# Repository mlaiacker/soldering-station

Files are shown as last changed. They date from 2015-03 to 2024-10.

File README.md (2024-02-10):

# Soldering Station for Weller Soldering Tips

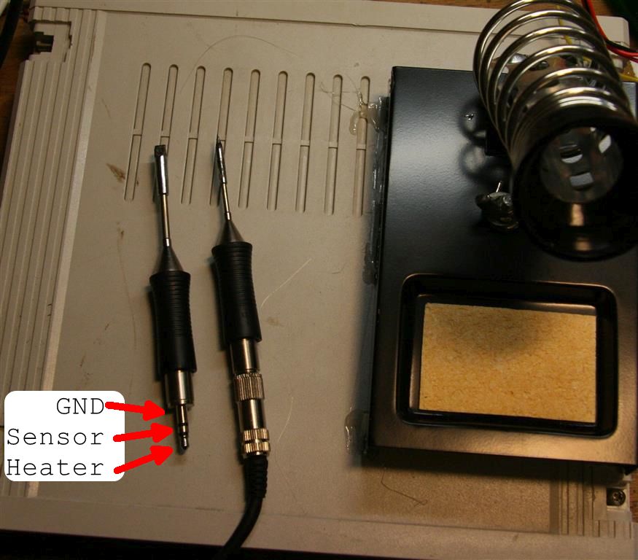
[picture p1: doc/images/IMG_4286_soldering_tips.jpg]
weller RT tips


https://www.weller-tools.com/eu/de/industrielles-loeten/produkte/loetspitzen/rtm-013-s

Power or Battery supply 10-14V DC up to 3A or so needed.

This project is based on the work of Martin Kumm.

http://www.martin-kumm.de/wiki/doku.php?id=05Misc:SMD_Solderstation

I made it simpler and cheaper. Instead of using an Arduino I use a ATmega8. This design doesn't use SMD instead a single sided PCB for easy assembly and cheap PCB production. The PCB is only 70x50mm. Instead of using two buttons to adjust the temperature I use a poti and optionally you can use a standard HD44780 compatible LCD to display temperatures. It runs on plain c (no arduino) and also includes supports a bootloader for easy firmware upgrade. The Bootloader has to be programmed befor soldering the mega8 into the PCB. The bootloader is activaded using the Boot pins on the PCB (short PD2 to ground)

http://mlaiacker.mooo.com/Elektronik/Soldering%20Station/

http://fpv-community.de/showthread.php?41335-DIY-SMD-L%F6tstation-Ersatz-f%FCr-%28WELLER%29

## PCB layout

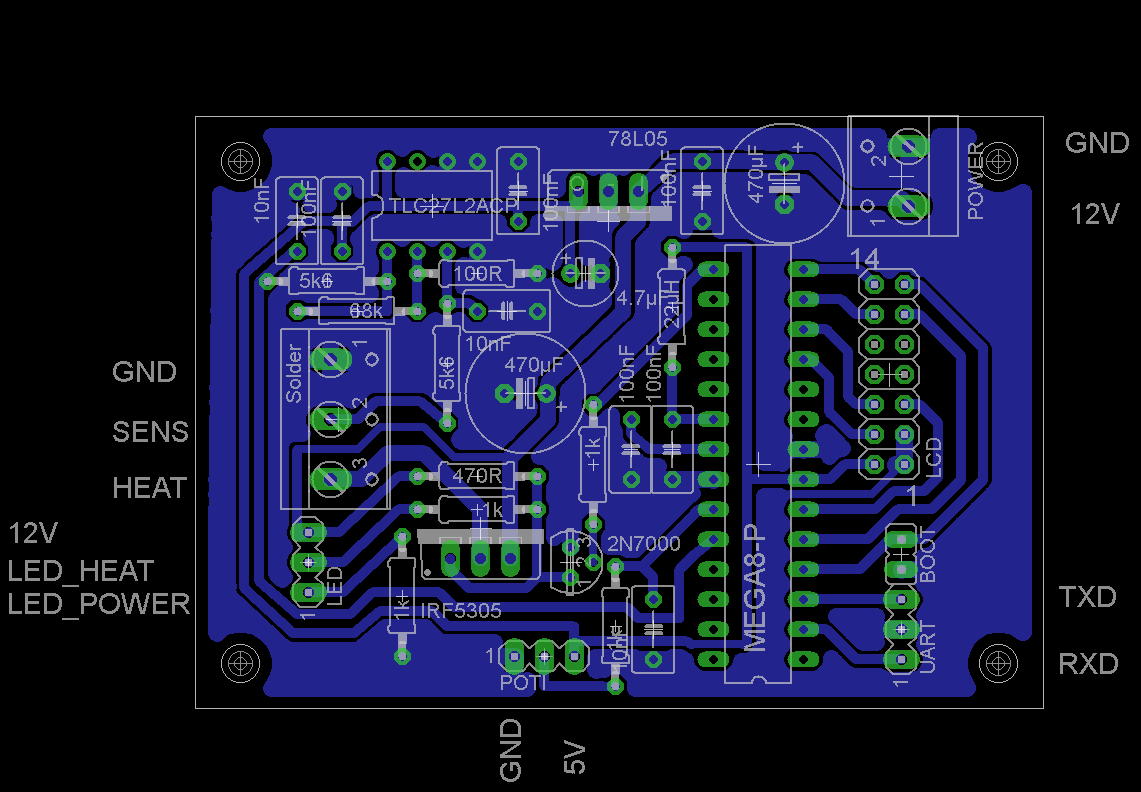
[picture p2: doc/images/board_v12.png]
Borad layout


[board layout pdf hardware/eagle/rt_solder_simple_V1.2.brd.pdf](hardware/eagle/rt_solder_simple_V1.2.brd.pdf?raw=true)

## Bill of Materials for PCB

[BOM as pdf](hardware/eagle/rt_solder_simple_V1.2.BOM.pdf?raw=true)

| Qty | Value | Device | Package | Parts | Description | Comment | Link |
| --- | --- | --- | --- | --- | --- | --- | ---- |
| 3 | 10nF | C-EU050-035X075 | C050-035X075 | C6, C7, C8 | CAPACITOR, | | |
| 5 | 100nF | C-EU050-035X075 | C050-035X075 | C3, C4, C9, C10, C11 | CAPACITOR, | | |
| 1 | TLC27L2ACP | TLC27L2ACP | DIL08 | IC3 | DUAL OPERATIONAL AMPLIFIERS | | |
| 1 | 22µH or 10R  | L-EU0207/10 | 0207/10 | L1 | INDUCTOR, | | |
| 1 | BOOT | JP1E | JP1 | JP2 | JUMPER | to enable bootloader | |
| 1 | MEGA8-P | MEGA8-P | DIL28-3 | IC1 | MICROCONTROLLER | needs bootloader | |
| 1 | 2N7000 N-CH  | VN2222KM | TO237 | Q1 | N-Channel MOSFET | | |
| 1 | IRF5305 P-CH | IRF9530 | TO220BV | Q3 | P-CHANNEL POWER-MOS-FET | | |
| 1 | LCD | PINHD-2X7 | 2X07 | JP1 | PIN HEADER | optional | |
| 1 | LED | MA03-1 | MA03-1 | SV4 | PIN HEADER | | |
| 1 | POTI | MA03-1 | MA03-1 | SV1 | PIN HEADER | Poti to set temperatur 1K-50K | |
| 1 | UART | MA03-1 | MA03-1 | SV2 | PIN HEADER | optional | |
| 1 | 4.7µF 10V | CPOL-EUE2.5-6 | E2,5-6 | C1 | POLARIZED CAPACITOR | | |
| 2 | 470µF 16V | CPOL-EUE3.5-10  | E3,5-10 | C2, C5 | POLARIZED CAPACITOR, | | |
| 1 | 100R | R-EU_0207/10 | 0207/10 | R6 | RESISTOR, | | |
| 1 | 470R | R-EU_0207/10 | 0207/10 | R2 | RESISTOR, | | |
| 1 | 68k | R-EU_0207/10 | 0207/10 | R5 | RESISTOR, | | |
| 2 | 5k6 | R-EU_0207/10 | 0207/10 | R4, R7 | RESISTOR, | | |
| 4 | 1k | R-EU_0207/10 | 0207/10 | R3, R8, R11, R12 | RESISTOR, | | |
| 1 | 47k | R-EU_0207/10 | 0207/10 | bodge | RESISTOR, | to fix tmperature measurement | |
| 1 | 10M | R-EU_0207/10 | 0207/10 | bodge | RESISTOR, | to fix tmperature measurement | |
| 1 | 10k | R-EU_0207/10 | 0207/10 | bodge | RESISTOR, | to add voltage measurement | |
| 1 | 100k | R-EU_0207/10 | 0207/10 | bodge | RESISTOR, | to add voltage measurement | |
| 1 | 78L05 | 78XXS | 78XXS | IC2 | VOLTAGE REGULATOR | | |
| 1 | POWER | W237-02P | W237-132 | X1 | WAGO SREW CLAMP | optional | |
| 1 | Solder | W237-3E | W237-3E | X2 | WAGO SREW CLAMP | optional | |

## Images

PCB<br>
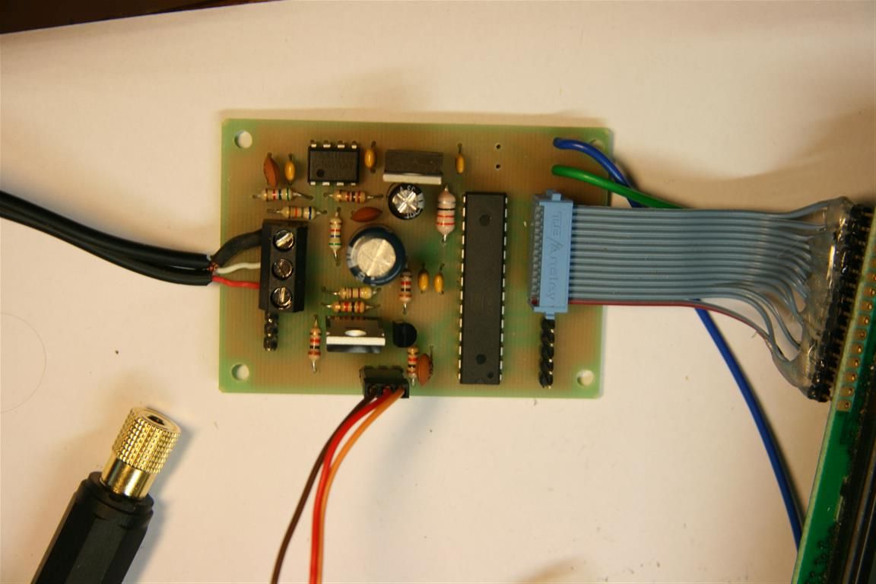
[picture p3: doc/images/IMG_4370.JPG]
max solder pcb
 <br>
With nice enclosure and LCD<br>
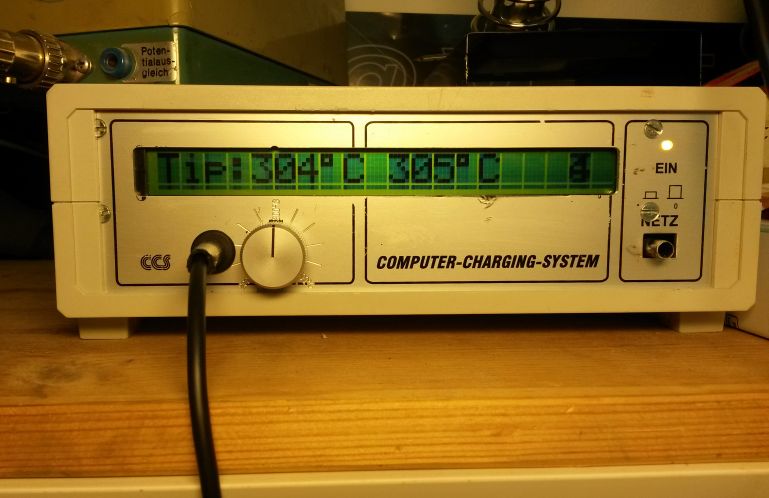
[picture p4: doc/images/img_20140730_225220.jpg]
 <br>
You can also just use this scale to set the temperature instead of the LCD
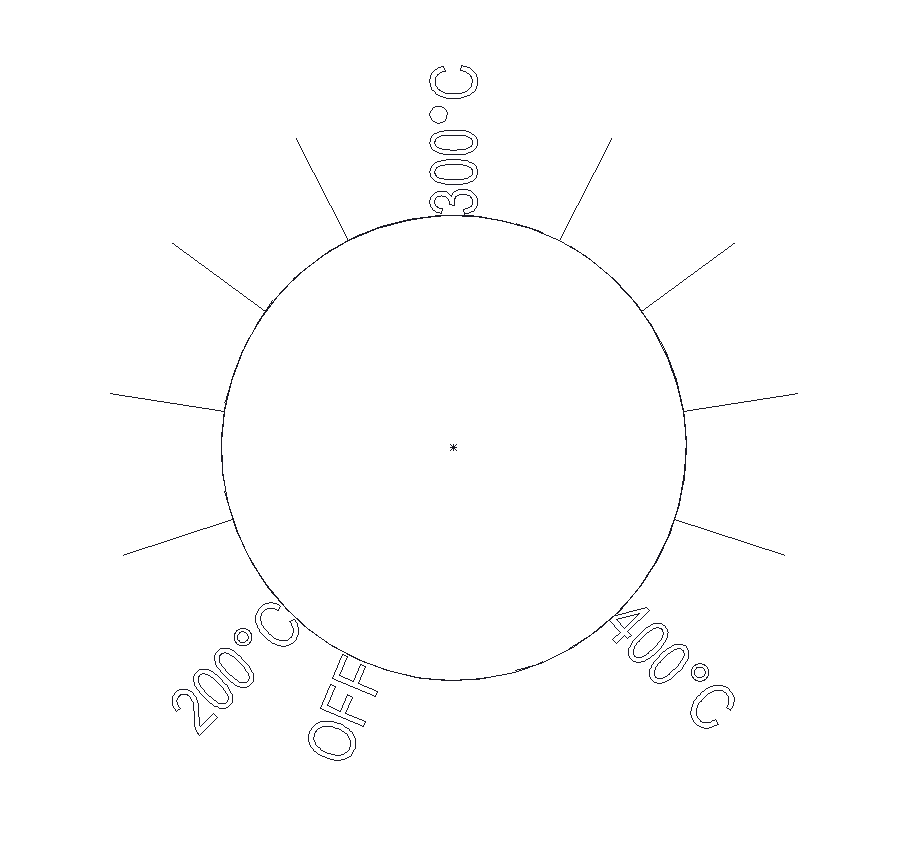
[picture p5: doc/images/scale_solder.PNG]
 <br>
Ask me for PCBs !! I had 10 made and some are available<br>
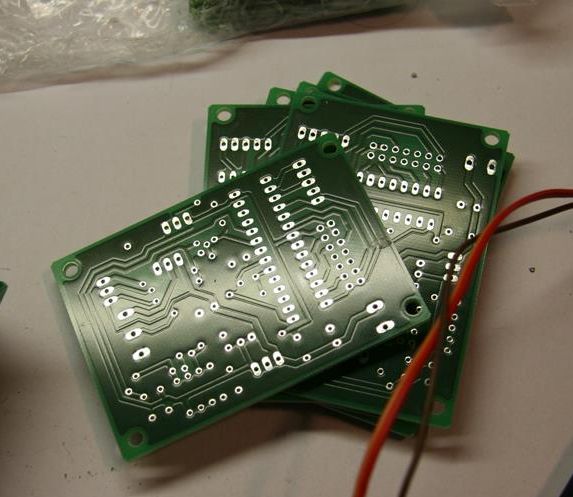
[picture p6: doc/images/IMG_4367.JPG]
PCBs
 <br>

## FAQ

### Hast du noch Platinen? 

ja noch: <br>
10 (2.4.2016)<br>
9 (5.4.2016)<br>
Ich kann auch gleich programmierten atmega8 und OPA und LCD dazu legen

### Was Kostet? 
10

### hex bauen?

```
make all
```

Das erstellen der main.hex geht über das Makefile mit "make all" dazu musst du den gcc avr Compiler installiert haben siehe dazu :http://www.mikrocontroller.net/articles/AVR-GCC

### flashen?

[for atmega 168](software/avr/main_atmega168.hex)

[for atmega 8](software/avr/main_atmega8.hex)

```
make program
```

Mit "make program" wird dann avrdude aufgerufen um über die serielle Schnittstelle ein neues Programm zu laden.
Dazu musst du wahrscheinlich den Port (com1) ändern im Makefile

```
AVRDUDE_PORT = com1 -b 38400 # programmer connected to serial device
```

Computer per TTL Seriell mit der Platine verbinden einen jumper auf die "Boot" pins stecken und einschalten dann wird der Bootloader aktiviert.

### bootloader ?

kopliziert. mit extra Adapter per ISP und dann mit "make programm_all" im bootloader Ordner. (avrdude und DIAMEX USB ISP bei mir)

### Wo bekomme ich IC3 her?

TLC 272 DIP bei reichelt

### Temperatur stimmt nicht

Die auf dem Display angezeigte Temperatur ist zu hoch bzw entspricht nicht der an der Lötspitze gemessenen. 
Bitte einen 47k Widerstand von Pin 3 an IC3 nach Masse löten und neue Software laden und wenn nötig
```C
#define TEMP_GAIN	(4980L)
#define TEMP_OFFSET	(-8)
```
anpassen.

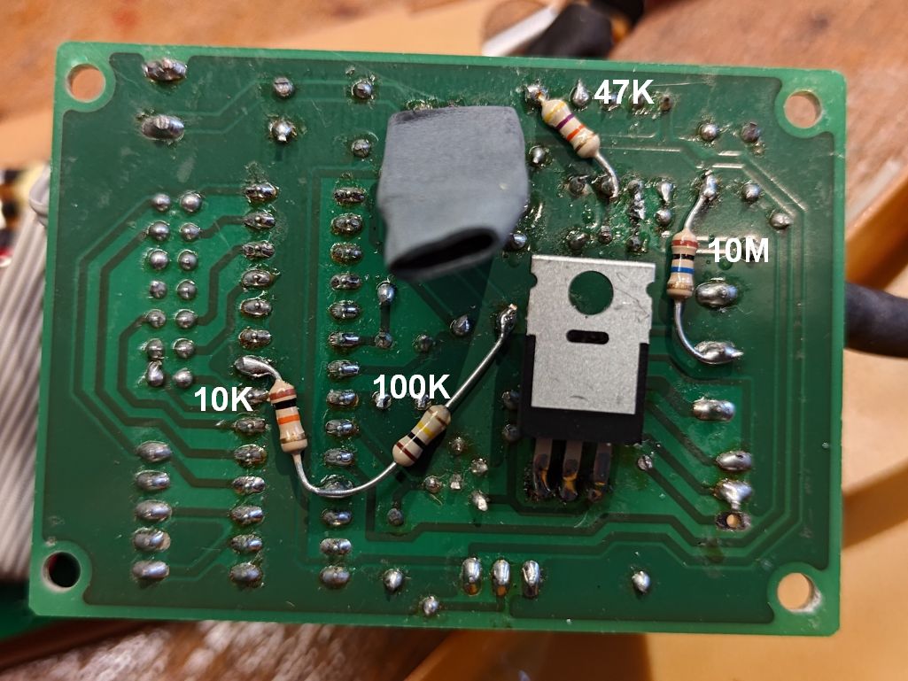
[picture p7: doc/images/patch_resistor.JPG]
PCB patch resitor placement
 <br>

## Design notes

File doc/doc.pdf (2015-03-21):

# Soldering Station for Weller Soldering Tips

This project is based on the work of Martin Kumm. (http://www.martin-kumm.de/wiki/doku.php?id=Projects:SMD_Solderstation)

I made it simpler and cheaper. Instead of using an Arduino I use a ATmega8. This design doesn't use SMD and one single Layer PCB for easy assembly and cheap PCB production and the PCB is only 70x50mm. Instead of using two Buttons to adjust the temperature I use a potentiometer and optionally you can use a standard HD44780 compatible LCD.

The PCB I designed is very easy to assemble and can also be home made. It has an optional LCD interface to display temperatures. The serial port can be used for monitoring, logging and firmware update.

These are the two tips I use for this project. They can be switched very easily and also heat up very fast.

I could not find a good and flexible cable for connecting the 3.5mm plug to the soldering station. You will need at least 3 wires and not too thin because the peak current is around 5A

I had some PCBs made and if someone wants some then please send me an e-mail.

This is one of the ordered PCB assembled and tested. While testing I wound a bug in my firmware and now it works better than before. I also made a video during the assembly.

The inside of the first prototype before installing the LCD. The transformer is from the battery charger that was in this enclosure before. It has a rated voltage of 12V at 5A. When using a smaller power supply and no LCD you can use a much smaller enclosure. Bu I had that laying around for more then 10 years and finally I found a new use for it.

This is the first prototype I made. The enclosure and the power supply I had laying around. On top you can see my old Ersa TE50 soldering station that I used to build the new one.

Front view of the prototype with LCD and the knob to adjust the temperature.

I used a CNC mill to make the holes and to engrave the scale for the temperature adjustment knob. The temperature can be adjusted from 200°C to 400°C. If you turn the nob below the 200 mark the heater is turned off.

This is a plot of the soldering iron heating up. Here for the big 50W tip. It only takes 14 seconds to heat up and here the heating current was limited to about 50%.

This is the response for the small tip and here it only needs 6 seconds to heat from room temperature to 340°C. It has a small overshoot when heating up from room temperature but I think it's the controller is tuned good enough. Maybe I could implement a estimator for the temperature but that would be overkill.

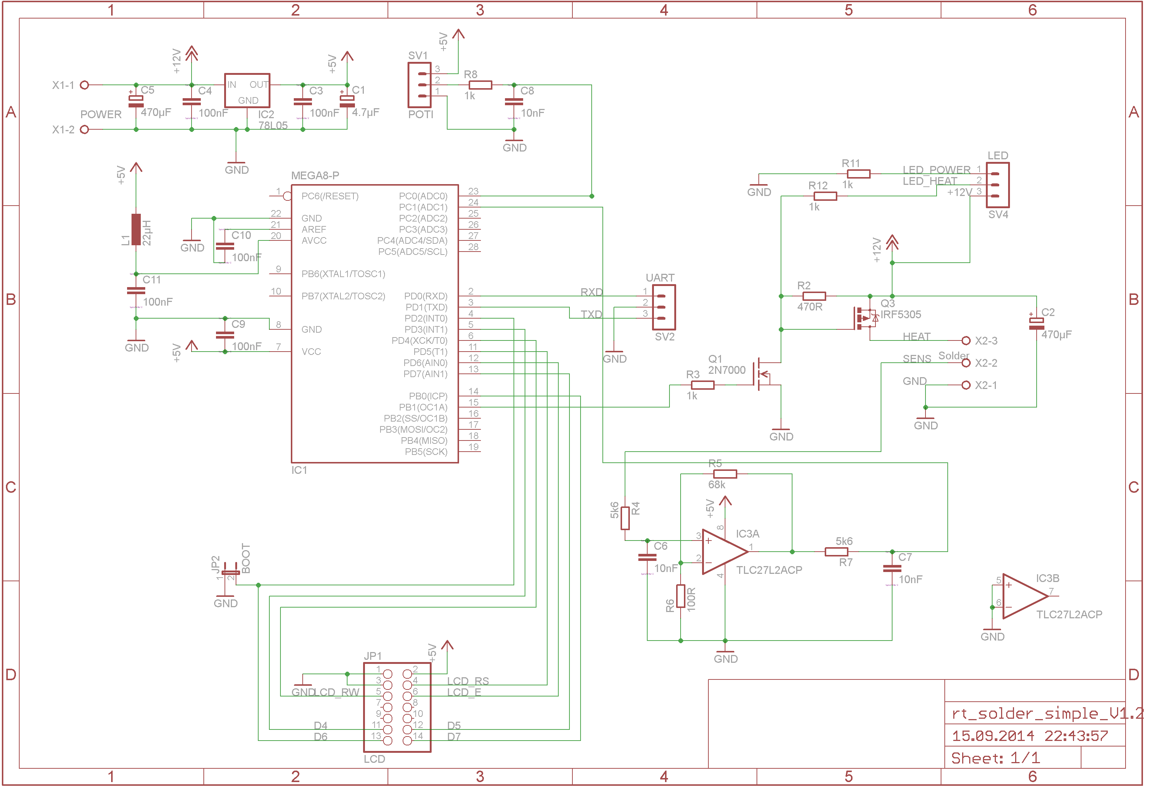
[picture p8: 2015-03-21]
hardware/eagle/schv12.png

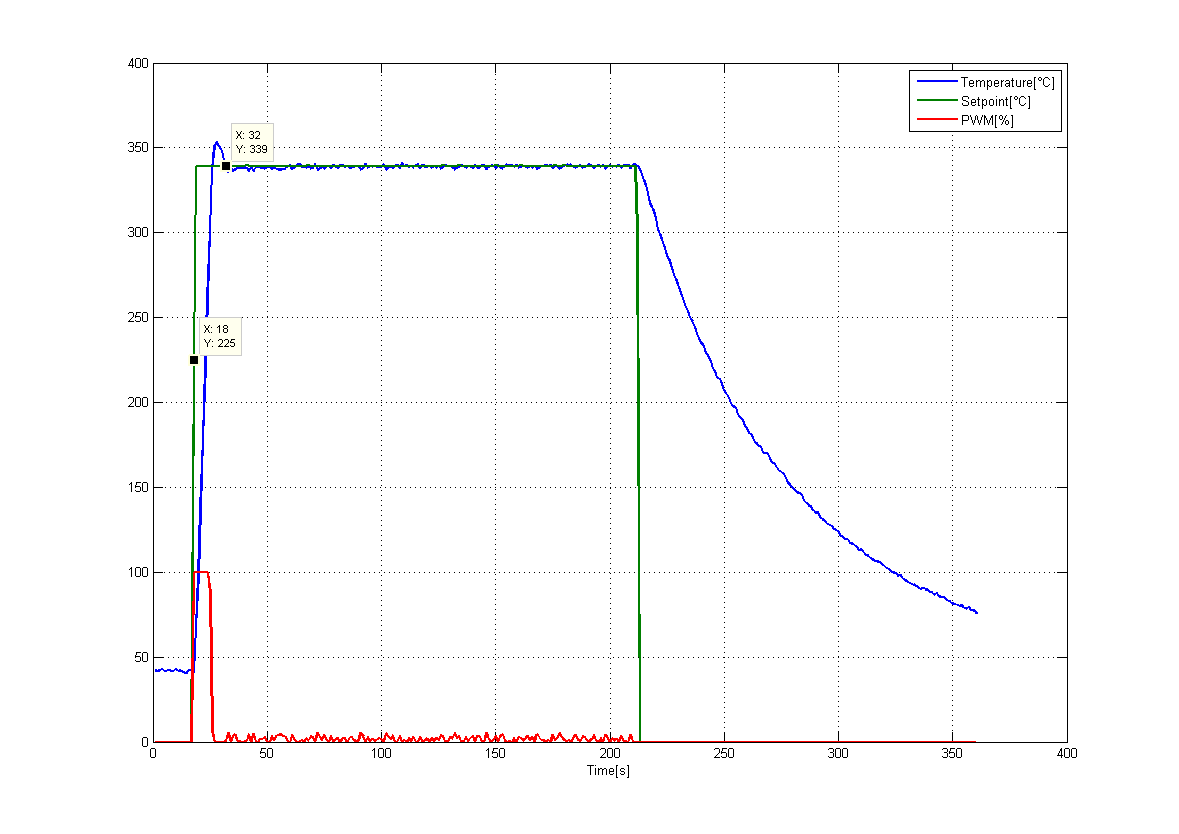
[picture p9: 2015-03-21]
doc/images/plot_tip1.png

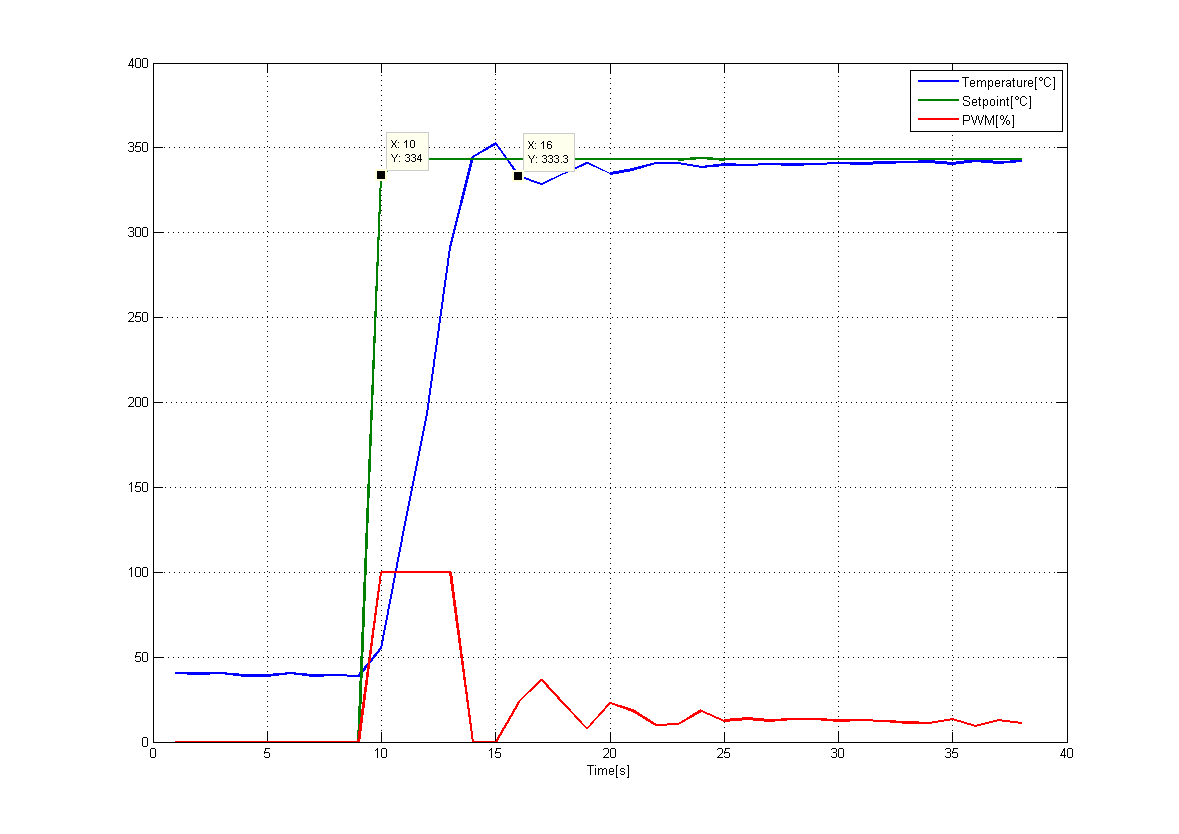
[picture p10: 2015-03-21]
doc/images/plot_tip2.png

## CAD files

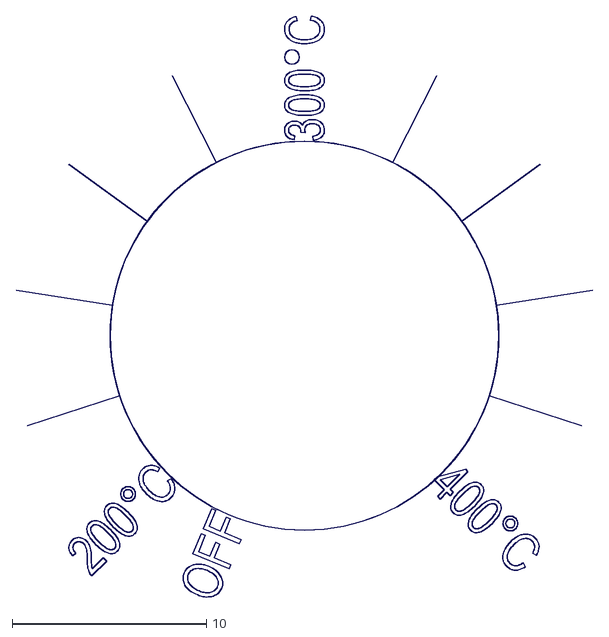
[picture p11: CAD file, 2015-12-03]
doc/images/scale_solder.DXF
29.6 x 29.9

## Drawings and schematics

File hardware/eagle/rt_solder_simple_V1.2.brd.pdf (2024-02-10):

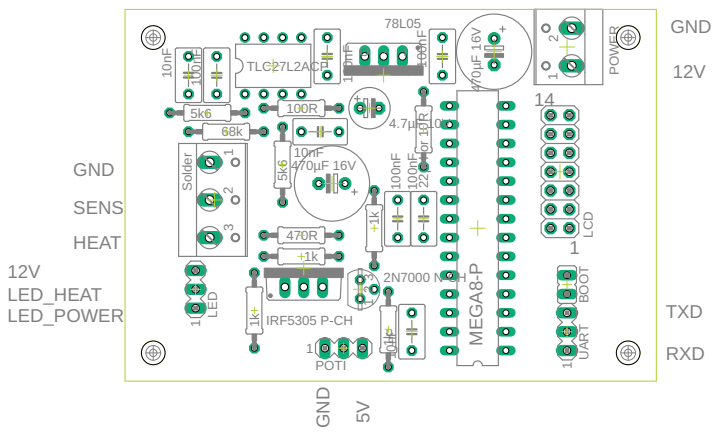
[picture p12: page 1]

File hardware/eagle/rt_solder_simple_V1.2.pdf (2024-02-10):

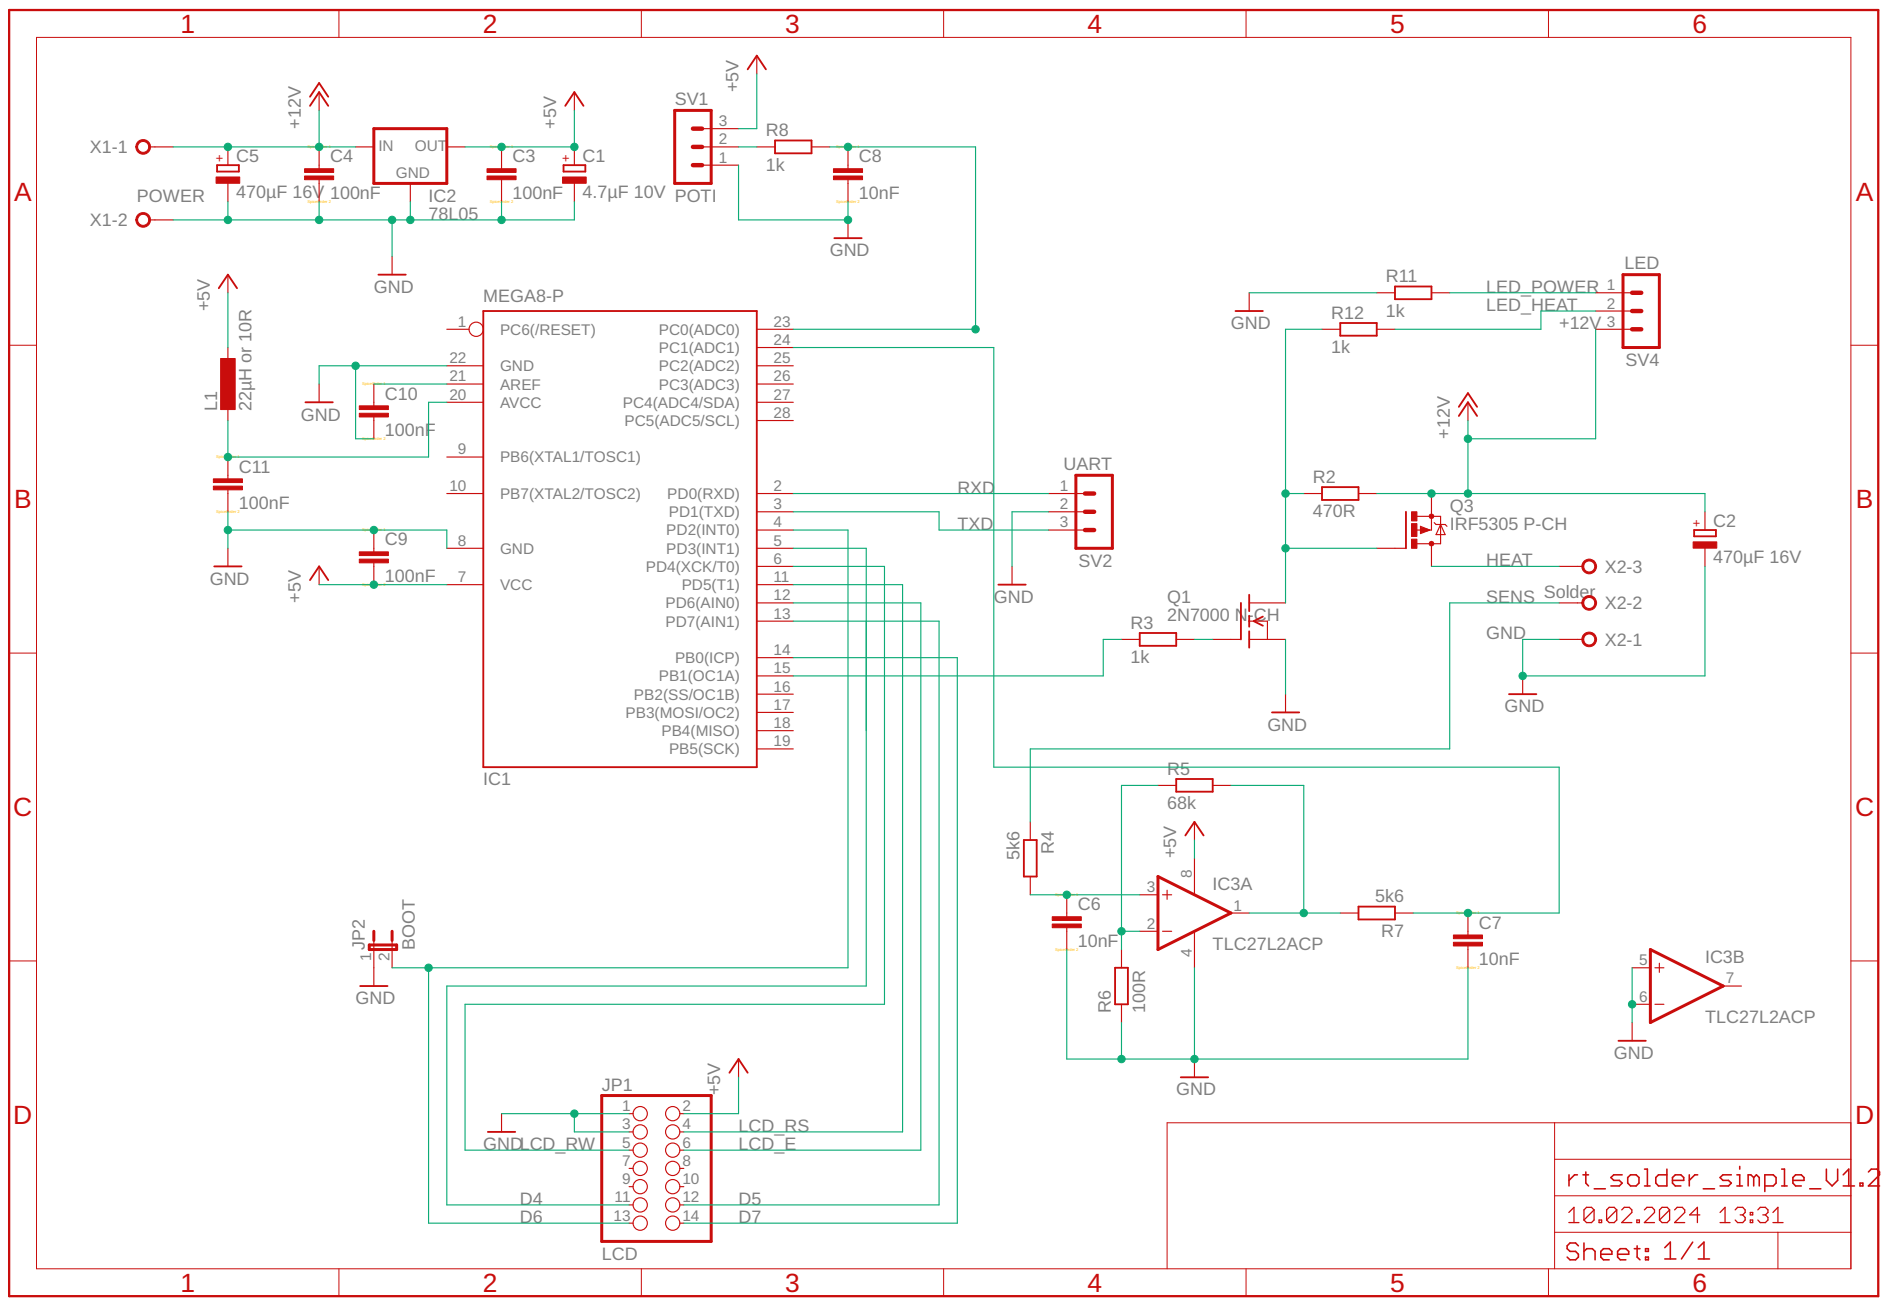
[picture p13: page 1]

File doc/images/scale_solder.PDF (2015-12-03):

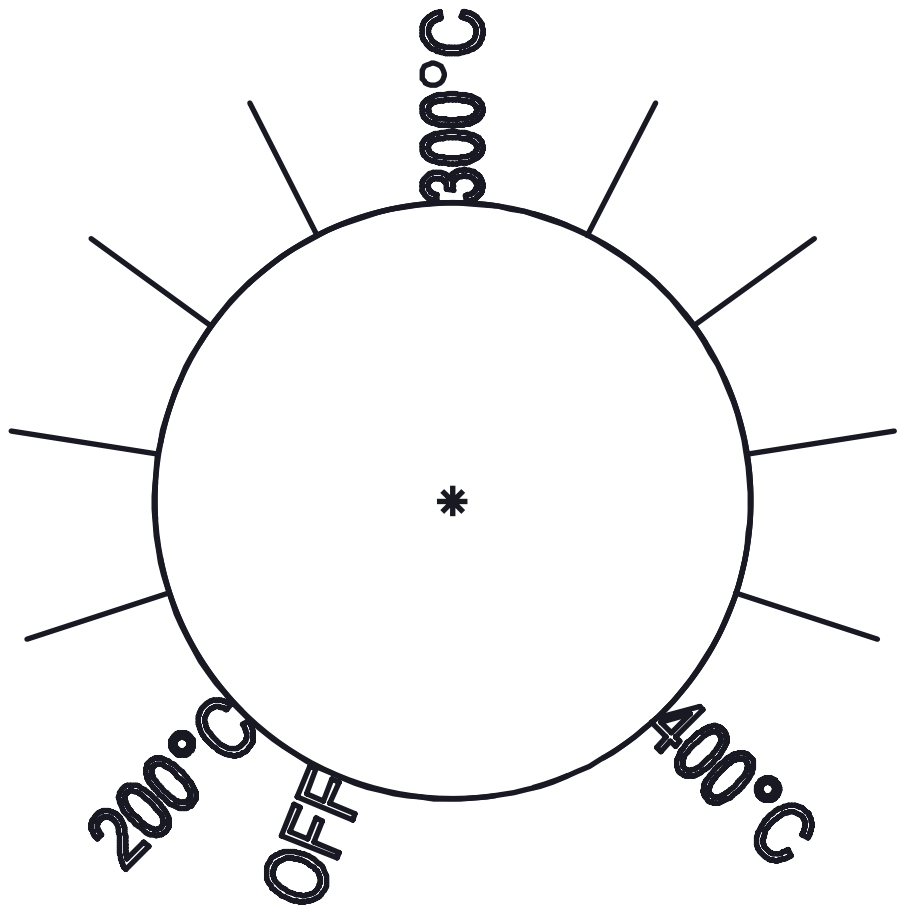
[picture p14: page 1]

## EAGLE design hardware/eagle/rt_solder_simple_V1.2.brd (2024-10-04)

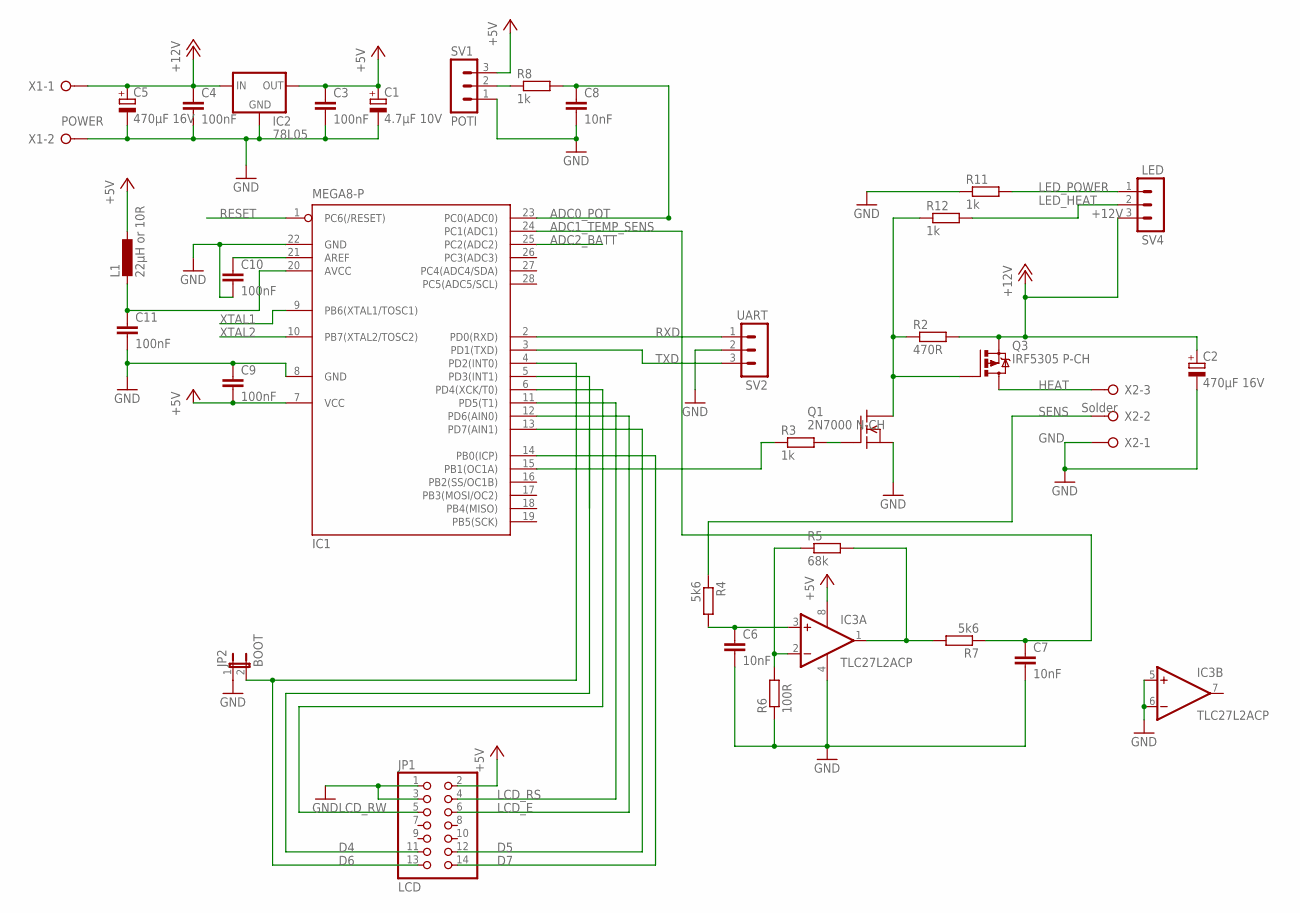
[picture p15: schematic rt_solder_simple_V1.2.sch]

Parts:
C1: 4.7µF 10V; E2,5-6
C2, C5: 470µF 16V; E3,5-10
C3, C4, C9, C10, C11: 100nF; C050-035X075
C6, C7, C8: 10nF; C050-035X075
IC1: MEGA8-P; DIL28-3
IC2: 78L05; 78XXS
IC3: TLC27L2ACP; DIL08
JP1: LCD; 2X07
JP2: BOOT; JP1
L1: 22µH or 10R; 0207/10
Q1: 2N7000 N-CH; TO237
Q3: IRF5305 P-CH; TO220BV
R2: 470R; 0207/10
R3, R8, R11, R12: 1k; 0207/10
R4, R7: 5k6; 0207/10
R5: 68k; 0207/10
R6: 100R; 0207/10
SV1: POTI; MA03-1
SV2: UART; MA03-1
SV4: LED; MA03-1
X1: POWER; W237-132
X2: Solder; W237-3E

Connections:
+5V: C1.+, C3.1, C9.2, IC1.7 (VCC), IC2.OUT, IC3.8 (VDD), JP1.2, L1.1, SV1.3
+12V: C2.+, C4.1, C5.+, IC2.IN, Q3.S, R2.2, SV4.3, X1.1
ADC0_POT: C8.1, IC1.23 (PC0(ADC0)), R8.2
ADC1_TEMP_SENS: C7.1, IC1.24 (PC1(ADC1)), R7.1
ADC2_BATT: IC1.25 (PC2(ADC2))
D4: IC1.5 (PD3(INT1)), JP1.11
D5: IC1.13 (PD7(AIN1)), JP1.12
D6: IC1.4 (PD2(INT0)), JP1.13, JP2.2
D7: IC1.14 (PB0(ICP)), JP1.14
GND: C1.-, C2.-, C3.2, C4.2, C5.-, C6.2, C7.2, C8.2, C9.1, C10.2, C11.2, IC1.8 (GND), IC1.22 (GND), IC2.GND, IC3.4 (GND), IC3.5 (+IN), IC3.6 (-IN), JP1.1, JP1.3, JP2.1, Q1.3 (S), R6.1, R11.1, SV1.1, SV2.2, X1.2, X2.1
HEAT: Q3.D, X2.3
LCD_E: IC1.12 (PD6(AIN0)), JP1.6
LCD_RS: IC1.11 (PD5(T1)), JP1.4
LCD_RW: IC1.6 (PD4(XCK/T0)), JP1.5
LED_HEAT: R12.2, SV4.2
LED_POWER: R11.2, SV4.1
unnamed: Q1.1 (D), Q3.G, R2.1, R12.1
unnamed: Q1.2 (G), R3.2
unnamed: C6.1, IC3.3 (+IN), R4.2
unnamed: IC3.2 (-IN), R5.1, R6.2
unnamed: IC3.1 (OUT), R5.2, R7.2
unnamed: IC1.15 (PB1(OC1A)), R3.1
unnamed: R8.1, SV1.2
unnamed: C11.1, IC1.20 (AVCC), L1.2
unnamed: C10.1, IC1.21 (AREF)
RESET: IC1.1 (PC6(/RESET))
RXD: IC1.2 (PD0(RXD)), SV2.1
SENS: R4.1, X2.2
TXD: IC1.3 (PD1(TXD)), SV2.3
XTAL1: IC1.9 (PB6(XTAL1/TOSC1))
XTAL2: IC1.10 (PB7(XTAL2/TOSC2))

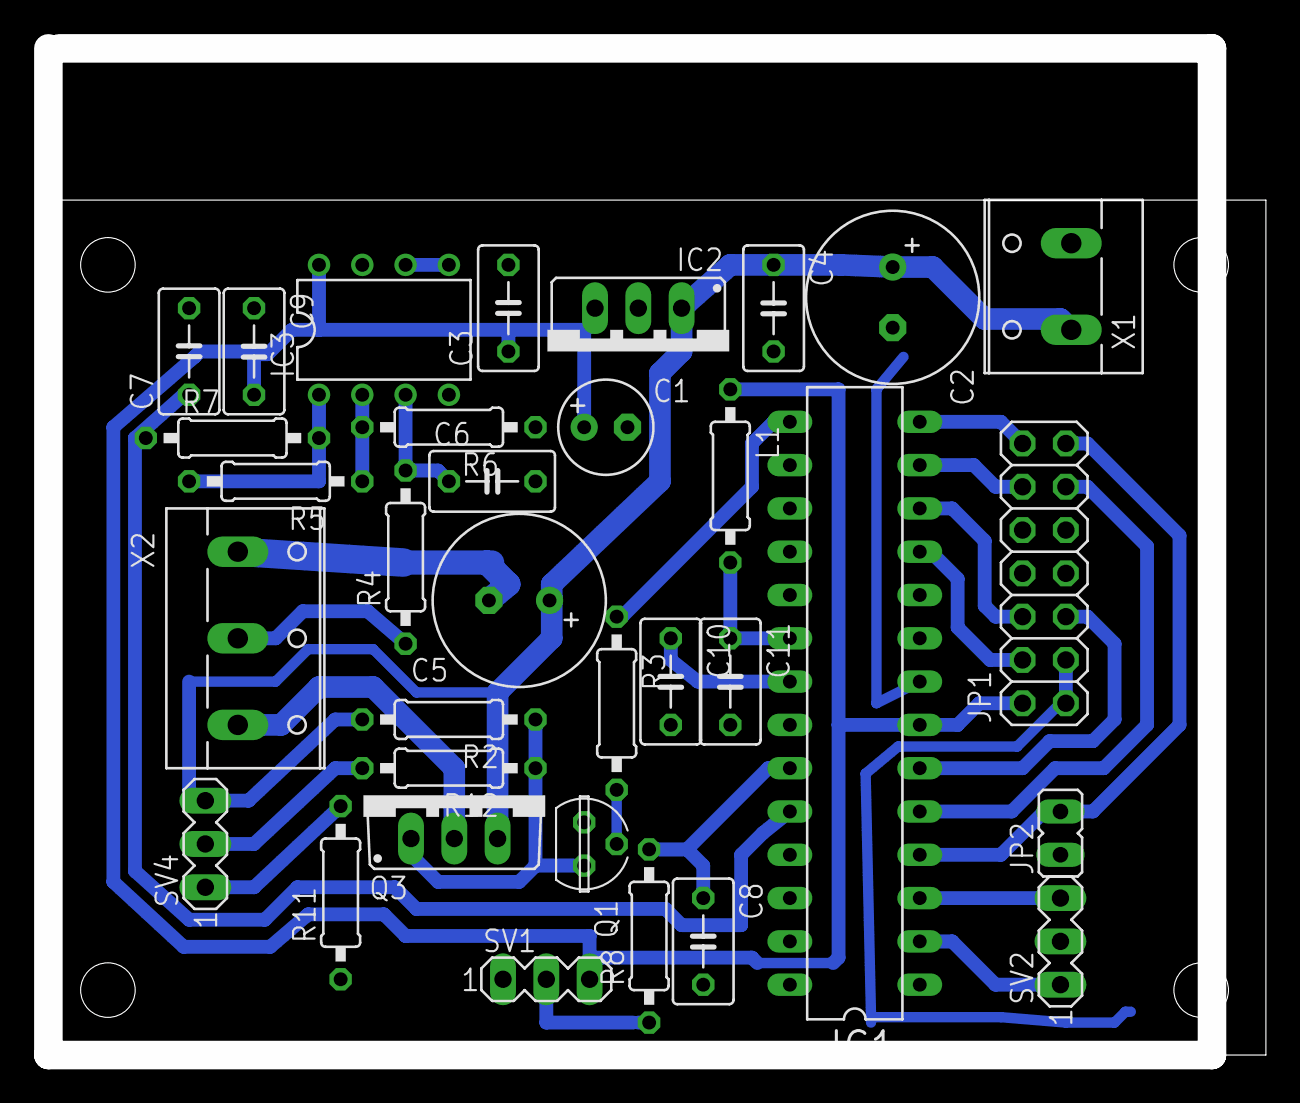
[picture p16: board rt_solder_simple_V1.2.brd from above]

Board: 2 copper layers, 71.7 x 50.2 mm, 33 parts (0 on the bottom side), 27 nets.

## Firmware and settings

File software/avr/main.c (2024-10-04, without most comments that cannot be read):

/*	 main.c
* max-Lader 
* entwickelt von:
* Maximilian Laiacker post@mlaiacker.de http://mlaiacker.de/
*
*/
#include <stdint.h>
#include <avr/interrupt.h>
#include <avr/io.h>
#include <avr/wdt.h> 
#include <avr/eeprom.h>

#include "global.h"
#include "usart.h"
#include "a2d.h"
#include "lcd.h"
#include "pwm.h"
#include "rtc.h"

#define LCD_2X16	1

#ifdef LCD_2X16
//#define LCD_SHOW_TIMEOUT // show timout counter (only on 2x16 LCD)
#endif

// for control
#define GAIN_KP 60L
#define GAIN_KI 1L
// for user input
#define POTI_OFF	10L			// bis zu diesem Wert Heizung aus
#define POTI_TEMP_START	200L	// Beginn das Poti temperatur bereich (L damit es keinen 16bit integer overflow gibt bei 1024*200/1024)
#define POTI_TEMP_END	400L	// Ende des Poti Temeratur bereich (Hardware erlaubt ca. 415 max)

#define SOLDER_MAX 	4100	// degC*10 2000==200.0degC Heizung abschalten wenn gemessene Temperatur so hoch ist
#define SOLDER_TEMP_STANDBY	(2000) // degC*10 2000==200.0degC
// gain
#define TEMP_GAIN	(4980L)
#define TEMP_OFFSET	(-8)
// standby
#define SOLDER_TIMEOUT		600 // seconds
#define SOLDER_TIMEOUT_OFF 	(SOLDER_TIMEOUT*10)
#define SOLDER_TIMEOUT_PWM_DIFF		20	// max pwm deviation around 10 second mean
#define SOLDER_TIMEOUT_TEMP_ERROR	50	// max temp deviation around setpoint in deg/10
// max heating power
#define SOLDER_MAX_PWM	(PWM_MAX_1A*2L/3L)

#define MENU_DISPLAY_INT	50 //ms
#define INT_CONTROL			16 //ms


struct
{
	t_Time tSekunde,tDisplay,tControl;
	char blinken;
	char menu_on;
	char menu_item;
} maindata;

struct {
	signed short pwm;
	signed short pwm_mean;
	signed short temp_des;
	signed short temp;
	int error_signal,i;
	char error;
	char standby;
	uint8_t	vinConnected; // voltage divider for input voltage measurement detected
	short Tpwm, Tstandby, Toff;

	char state;
	char on;
	unsigned short poti, poti_old;
	uint16_t	vin_dV; // input voltage in deci Volt
	uint16_t	vinSum;
	uint16_t    vinCount;
} solder;

typedef struct
{
	unsigned short pwm_max; // in prozent 10..99
	unsigned char poti_offset; // in adc ticks 0..1023
	unsigned char lcd_mode; // 0 = disable 1 = 1x20 2=2x16
	unsigned char control_freq; // temperature measurment freq 4..50
	unsigned short temp_low; // minimal temp for poti in deg c 1..SOLDER_MAX/10
	unsigned short temp_high; // max temp for poti 1..SOLDER_MAX/10
	unsigned short standby_timeout; // in seconds 0..6000 10<disable
	unsigned short standby_temp; // in deg c 1..temp_high
	unsigned short standby_fact; // in fact from 0..10 0=disable 5 = normal 10=big changes will reset standby counter
	short control_p; // control p gain 1..100
	short control_i; // control i gain 0..10
	short temp_sens_offset; // -100..100
	short temp_sens_gain; // 3000..6000
	unsigned int checksum; //sum off all values  + 0xabcdef
} solder_param_t;

solder_param_t param;
solder_param_t param_ee EEPROM;

unsigned int paramChecksum(solder_param_t *param);
void paramSave(void);
void paramLoad(void);

void uartOutputHeader(void);
void uartOutput(void);


//-------------Initalisierung------------------
// da die init fuktionen sowiso nur ein mal im programm aufgerufen werden stehen sie hier "inline"

void init(void){
	#ifdef BEEP_ON
	BEEP_INIT;
	#endif
	
	#ifdef UART
// Serielle Schnittstelle intalisieren
	#if defined (__AVR_ATmega168__)
		UBRRL = (uint8_t)(F_CPU/(UART_BAUD_RATE*8L)-1);
		UBRRH = (F_CPU/(UART_BAUD_RATE*8L)-1) >> 8;
		UCSR0A = _BV(U2X0);
		UCSR0B = _BV(TXEN)|_BV(RXEN)|_BV(RXCIE);
                       // Receiver enabled, Transmitter enabled
                       // RX Complete interrupt enabled
	#elif defined (__AVR_ATmega8__)
		UBRRL = (uint8_t)(F_CPU/(UART_BAUD_RATE*8L)-1);
		UBRRH = (F_CPU/(UART_BAUD_RATE*8L)-1) >> 8;
		UCSRA = _BV(U2X);
		UCSRB = _BV(TXEN)|_BV(RXEN)|_BV(RXCIE); // rx, tx, rx int
		sbi(PORTD,0);// enable pull up on rx pin
	#endif

	#endif

	Time=0;
	// Counter Register
	TCNT0=RTC_START_VAL;
	// Overflow enable
	#ifdef TIMSK
	TIMSK |= _BV(TOIE0);
	#else
	TIMSK0 |= _BV(TOIE0);
	#endif
	#ifdef TCCR0
	// prescaler select F_CPU/256
	// ergibt einen overflow alle 16MHz/256/250 = 4 ms
#if RTC_PRESCALER == 256
	TCCR0 = 0x04;
#elif RTC_PRESCALER == 64
	TCCR0 = 0x03;
#endif
	#else
	TCCR0B = 0x04;
	#endif
	
	
	ADMUX = (0<<ADLAR) | (ADC_REFERENCE<<6);
	ADCSR = ((0<<ADFR)|(1<<ADEN)|(1<<ADIE)|(1<<ADSC)|(1<<ADIF) | ADC_PRESCALE);

	pwmInit1A();
  
	sei(); // interupt enable

	//TASTE_M_INIT;
	wdt_enable(WDTO_1S);

	wdt_reset();
	paramLoad();
	if(param.checksum != paramChecksum(&param))
	{
	 // defaults
		usartPrint("loading default params...\r\n");
		param.control_p = GAIN_KP;
		param.control_i = GAIN_KI;
		param.control_freq = 10;
		param.poti_offset = POTI_OFF;
		param.lcd_mode = 1;
		param.pwm_max = SOLDER_MAX_PWM;
		param.standby_fact = 5;
		param.standby_temp = 200;
		param.standby_timeout = 600;
		param.temp_high = POTI_TEMP_END;
		param.temp_low = POTI_TEMP_START;
		param.temp_sens_gain = TEMP_GAIN;
		param.temp_sens_offset = TEMP_OFFSET;
		paramSave();
	}
	solder.vinConnected = 1;
	wdt_reset();
	usartPrint("# Max Solder build date:"__DATE__);
	usartPrint(", Git version: "GIT_VERSION"\r\n");

#ifdef LCD_CLR
	wdt_reset();
	lcdInit();
	rtcDelay(100);
	wdt_reset();
	lcdGotoY(0);
	#if defined (__AVR_ATmega168__)
		lcdPrint("   MAX-Solder16  ");
	#elif defined (__AVR_ATmega8__)
		lcdPrint("   MAX-Solder    ");
	#endif
#ifdef LCD_2X16
	lcdGotoY(1);
	lcdPrint("B:"__DATE__);
#endif
	wdt_reset();
	rtcDelay(300);
	wdt_reset();
	rtcDelay(300);
	wdt_reset();
	rtcDelay(300);
	wdt_reset();
	lcdGotoY(1);
	lcdPrint("Git:"GIT_VERSION"     ");
	rtcDelay(300);
	wdt_reset();
	rtcDelay(300);
	wdt_reset();
#endif
	uartOutputHeader();
}// init end

/*---------------- Functions -------------------------*/
void paramSave(void)
{
		param.checksum = paramChecksum(&param);
		eeprom_write_block(&param, &param_ee, sizeof(param));
}

void paramLoad(void)
{
	eeprom_read_block(&param,&param_ee,sizeof(param));
}

unsigned int paramChecksum(solder_param_t *param)
{
	unsigned int result = 0xabcd,i;
	for(i=0;i<sizeof(*param)-sizeof(param->checksum);i++)
	{
		result += ((unsigned char*)param)[i];
	}
	return result;
}

#ifdef UART

void uartOutputHeader(void)
{
	usartPrint("\r\ntemp temp_desired pwm timeout Vin\r\n");
}

void uartOutput(void)
{
	usartNum(solder.temp,4,1); // Temp
	usartNum(solder.temp_des,4,1); // Ausgangsstrom
	usartNum(solder.pwm,3,0);
	usartNum(solder.Toff,4,0);
	usartNum(solder.vin_dV,3,1);
	usartPutc('\r');
	usartPutc('\n');
}

int paramEdit(int param, int step , int min, int max, char key){
	if(key=='+'){
		param += step;
	}
	if(key=='-'){
		param -= step;
	}
	param = MAX(min, param);
	param = MIN(max, param);
	return param;
}

void uartMenu(char key)
{
	if(maindata.menu_item == 0)
	{
		if(key>='1' && key<='9')
		{
			maindata.menu_item = key - '0';
		} else {
			usartPrint("Solder Menu:\r\n");
			usartPrint("## PARAMTER ## (select 1-9 and then +- to edit)");
			usartPrint("\r\n1 P=");usartNum(param.control_p,3,0);
			usartPrint("\r\n2 I=");usartNum(param.control_i,3,0);
			//usartPrint("\r\n4 interval=");usartNum(param.control_freq,3,0);
			usartPrint("\r\n5 sens gain=");usartNum(param.temp_sens_gain,5,0);
			usartPrint("\r\n6 sens offset=");usartNum(param.temp_sens_offset,4,0);
			usartPrint("\r\nsave:s");
			usartPrint("\r\nload:l");
			usartPrint("\r\nexit:q\r\n");
		}
	} 
	{
		switch (maindata.menu_item)
		{
		case 1:
			param.control_p = paramEdit(param.control_p, 1, 1, 200, key);
			usartPrint("\r\n1 P=");usartNum(param.control_p,3,0);
			break;

		case 2:
			param.control_i = paramEdit(param.control_i, 1, 0, 20, key);
			usartPrint("\r\n2 I=");usartNum(param.control_i,3,0);
			break;
		case 5:
			param.temp_sens_gain = paramEdit(param.temp_sens_gain, 10, 3000, 6000, key);
			usartPrint("\r\n5 sens gain=");usartNum(param.temp_sens_gain,5,0);
			break;
		case 6:
			param.temp_sens_offset = paramEdit(param.temp_sens_offset, 2, -100, 100, key);
			usartPrint("\r\n6 sens offset=");usartNum(param.temp_sens_offset,4,0);
			break;
		
		default:
			break;
		}
	}
	if(key=='q'){
		maindata.menu_on = 0;
		uartOutputHeader();
		maindata.menu_item = 0;
	} 
	if(key=='s'){
		paramSave();
		maindata.menu_on = 0;
		uartOutputHeader();
		maindata.menu_item = 0;
	} 
	if(key=='l'){
		paramLoad();
		maindata.menu_item = 0;
	} 
}

#endif
/*----------------------------------------------------*/

/*----------------Timer Interrupts--------------------*/
ISR(TIMER0_OVF_vect)
{
  TCNT0=RTC_START_VAL;
  Time+=RTC_OVERFLOW_TIME;
}
/*----------------------------------------------------*/

/*----------------Main Loop---------------------------*/
int main(void)
{
	init();
	// watchdog einschalten
	char last_char=0,c=0;
	for(;;)
	{
		wdt_reset();
#ifdef UART
		if(usart_unread_data()!=0)
		{
			if(!maindata.menu_on)
			{
				last_char =c;
				c=usart_getc();
				if(c=='m'){
					maindata.menu_on = 1;
					uartMenu(0);
				}
				if(last_char==0x30 && c==0x20){
					rtcDelay(300);
					usartPutc(0x14);
					rtcDelay(30);
					usartPutc(0x10);
					while(1) { c++;}; // reset into bootloader
				}

			} else
			{
				solder.on = 0;
				solder.standby = 1;
				uartMenu(usart_getc());
			}
		}
#endif
		if(maindata.tControl <= Time)
		{
			solder.state++;
			if(solder.state==1)
			{
				// heizung aus um Temperatur zu messen
				pwmSet1A(0);
			} else if (solder.state==4)
			{
				// Temperatur messen und Heizung immer noch aus.
				solder.temp =  ((a2dConvert10bit(ADC_CH_TEMP)*((long)param.temp_sens_gain)/(ADC_MAX*1L) + param.temp_sens_offset) + solder.temp)/2;
				if(solder.temp>SOLDER_MAX)
				{
					solder.state = 1;
				}
			} else if (solder.state==5)
			{
				// Temperatur noch mal messen und Ergebnisse mitteln
				solder.temp =  ((a2dConvert10bit(ADC_CH_TEMP)*((long)param.temp_sens_gain)/(ADC_MAX*1L) + param.temp_sens_offset) + solder.temp)/2;
				if(solder.temp>SOLDER_MAX)
				{
					solder.state = 1;
				}
			}
			if (solder.state>=5)
			{
				// Heizung wieder aktivieren
				pwmSet1A(solder.pwm);
			}
			if (solder.state > 16) solder.state = 0; // neue messung starten

			if(solder.on && solder.error == 0)
			{
				// PI Temperaturregelung
				solder.error_signal = (solder.temp_des - solder.temp);
				solder.pwm = (solder.i + solder.error_signal*GAIN_KP)/100L;
				// anti wind-up
				if(solder.pwm >= -SOLDER_MAX_PWM && solder.pwm < SOLDER_MAX_PWM)
				{
					// Integral anteil
					solder.i += solder.error_signal*GAIN_KI/10L;//*INT_CONTROL/1000L;
					if(solder.i<0) solder.i = 0;
				}
				// min und max abfangen
				if(solder.pwm>SOLDER_MAX_PWM) solder.pwm=SOLDER_MAX_PWM;
				if(solder.pwm<0) solder.pwm=0;
			} else
			{
				solder.pwm = 0;
				solder.i = 0;
			}

			maindata.tControl += INT_CONTROL;
		}
		if(maindata.tDisplay <= Time)
		{
			solder.poti  = (a2dConvert10bit(ADC_CH_POTI) + a2dConvert10bit(ADC_CH_POTI))/2;
			solder.vinSum += a2dConvert10bit(ADC_CH_VBAT);
			solder.vinCount++;
			if(solder.poti<POTI_OFF)
			{

				solder.on = 0;
				solder.temp_des = 0;
				solder.error = 0;
				solder.standby = 0;
			} else
			{
				if(solder.standby)
				{
					solder.temp_des = SOLDER_TEMP_STANDBY;
				} else
				{
					// Soll-Temperatur Berechnung aus Wert vom Poti
					solder.on = 1;
					solder.temp_des = (POTI_TEMP_START + (solder.poti-POTI_OFF)*(POTI_TEMP_END-POTI_TEMP_START)/(ADC_MAX-POTI_OFF))*10;
				}
			}
			lcdGotoY(0);
			// Ist-Temperatur
			lcdPrint("Temp:");
			lcdNum(solder.temp/10,3,0);
			lcdDataWrite(223);
			lcdPrint("C ");
			// Soll-Temperatur
			lcdNum(solder.temp_des/10,3,0);
			lcdDataWrite(223);
			lcdPrint("C ");
#ifdef LCD_2X16
			lcdGotoY(1); // goto 2. line
			lcdPrint(" PWM:"); // Den text nur wenn 2x16 LCD angeschlossen
#endif
			if(solder.error)
			{
				lcdPrint("ERR");
			} else
			{
				if(maindata.blinken && solder.standby)
				{
					// Standby Zustand anzeigen
					lcdPrint("STA");
				} else
				{
					// PWM in Prozent anzeigen 0..99
					lcdNum(MIN(99,solder.pwm*10/((SOLDER_MAX_PWM)/10)),2,0);
					lcdPrint("%");
				}
			}
#if defined(LCD_2X16) && defined(LCD_SHOW_TIMEOUT)
			lcdPrint(" T:");
			lcdNum(solder.Toff,5,0); // standby timeout counter [s]
#endif
#if defined(LCD_2X16) && !defined(LCD_SHOW_TIMEOUT)
			if(solder.vin_dV>50)
			{
				lcdPrint(" ");
				if(solder.Toff>9 && (solder.Toff%2==0))
				{
					lcdDataWrite('0'+(solder.Toff/100)%10);
				} else lcdPrint(" ");

				lcdNum(solder.vin_dV, 4, 1); // input voltage
				lcdPrint("V");
			}
#endif

			maindata.tDisplay += MENU_DISPLAY_INT;
		}
		if(maindata.tSekunde <= Time) // jede sekunde
		{
			if(solder.vinConnected)
			{
				solder.vin_dV = (solder.vinSum/solder.vinCount)*50/93;
				if(solder.vin_dV<50 && solder.vinCount>5)
				{
					solder.vinConnected = 0;
				}
			}
			else
				solder.vin_dV = 0;
			solder.vinSum = 0;
			solder.vinCount = 0;
			if(solder.on)
			{
				if(solder.vin_dV>50 && solder.vin_dV<75 && solder.vinConnected)
				{
					solder.error = 1;
				}
				if(einschaltverz(solder.pwm >= SOLDER_MAX_PWM, 20, &solder.Tpwm))
				{
					// bei zu lange volle power muss ein fehler vorliegen und die Heizung wird abgeschaltet
					solder.error = 1;
					solder.standby = 0;
					solder.Tstandby = 0;
				} else
				{
					solder.pwm_mean = (solder.pwm_mean*9 + solder.pwm)/10;
					/* Standby Bedingungen:
					 * 1: abs(solder.poti - solder.poti_old)<10 Soll Temperatur Einstellung �ndert sich nicht.
					 * 2: (solder.pwm < solder.temp_des/65)  Der PWM wert zum heizen ist klein (wenn man den L�tkolben benutzt muss ja st�rker geheizt werden als wenn er nur rum liegt)
					 * 3: (solder.error_signal < 50) Die ist Temperatur ist maximal 5 Grad C kleiner als die soll Temperatur.
					 */
//					char standby = (solder.pwm < solder.temp_des/65) && (solder.error_signal < 50) && (abs(solder.poti - solder.poti_old)<10);
					char standby = (abs(solder.pwm - solder.pwm_mean)<SOLDER_TIMEOUT_PWM_DIFF || solder.pwm<=1) && (solder.error_signal <= SOLDER_TIMEOUT_TEMP_ERROR) && (abs(solder.poti - solder.poti_old)<=11);

					solder.standby = einschaltverz(standby,	SOLDER_TIMEOUT, &solder.Tstandby);

					if(einschaltverz(standby,SOLDER_TIMEOUT_OFF, &solder.Toff)) solder.on = 0;
				}
				solder.poti_old = solder.poti;
			} else {
				solder.Tstandby = 0;
			}
			maindata.tSekunde += 1000L;
			maindata.blinken = !maindata.blinken;
			#ifdef UART
				if(!maindata.menu_on) uartOutput();
			#endif
		}

	}// for(ever) 
}// main

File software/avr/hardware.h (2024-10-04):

#ifndef HARDWARE_H
#define HARDWARE_H

#if defined (__AVR_ATmega168__)
#include "migration8-168.h"
#endif

#define PROG_VERSION	(16)

#ifndef F_CPU
	#if defined (__AVR_ATmega168__)
		#define F_CPU        8000000L              		// 8MHz processor
	#elif defined (__AVR_ATmega8__)
		#define F_CPU        8000000L               		// 16MHz processor
	#endif
#endif

/* ### ADC ### */

#define ADC_CH_TEMP		1
#define ADC_CH_POTI		0
#define ADC_CH_VBAT		2


#define ADC_U_REF	500L // in mv/10
#define ADC_MAX		(1024L)

#define ADC_PRESCALE			ADC_PRESCALE_DIV128
// Refferenzspannung 5.0V
#define ADC_REFERENCE			ADC_REFERENCE_AVCC

#define A2D_SCAN_CHANNELS	(2)
#define A2D_SCAN_BUF	(16)

// oversampling benutzen statt laufende mittelwert bildung
//#define OVERSAMPLING
#define OVERSAMPLING_RATE		8

/* ### Beep ### */
/*
#define BEEP_DDR		DDRB
#define BEEP_PORT		PORTB
#define BEEP_BIT		0
#define BEEP_ON			sbi(BEEP_PORT,BEEP_BIT)
#define BEEP_OFF		cbi(BEEP_PORT,BEEP_BIT)
#define BEEP_INIT		(BEEP_DDR |= (1<<BEEP_BIT))
*/

/* ### LCD ### */
#define LCD_PORT_INTERFACE
#define LCD_CTRL_PORT	PORTD
#define LCD_CTRL_DDR	DDRD
#define LCD_CTRL_RS		5
#define LCD_CTRL_RW		4
#define LCD_CTRL_E		6
#define LCD_CTRL_E_PORT	PORTD
#define LCD_CTRL_E_DDR	DDRD
// port you will use for data lines
#define LCD_DATA_PORT_D4	PORTD
#define LCD_DATA_DDR_D4		DDRD
#define LCD_DATA_PIN_D4		PIND
#define LCD_DATA_D4		3
#define LCD_DATA_PORT_D5	PORTD
#define LCD_DATA_DDR_D5		DDRD
#define LCD_DATA_PIN_D5		PIND
#define LCD_DATA_D5		7
#define LCD_DATA_PORT_D6	PORTD
#define LCD_DATA_DDR_D6		DDRD
#define LCD_DATA_PIN_D6		PIND
#define LCD_DATA_D6		2
#define LCD_DATA_PORT_D7	PORTB
#define LCD_DATA_DDR_D7		DDRB
#define LCD_DATA_PIN_D7		PINB
#define LCD_DATA_D7		0

// access mode you will use (default is 8bit unless 4bit is selected)
#define LCD_DATA_4BIT

#define LCD_LINES				1	// visible lines
#define LCD_LINE_LENGTH			20	// line length (in characters)

#define LCD_DELAY	asm volatile ("nop\n nop\n nop\n nop\n nop\n nop\n nop\n nop\n");
//#define LCD_DELAY	asm volatile ("nop\n nop\n nop\n nop\n nop\n nop\n nop\n");

/* ### Tasten ### */
#define TASTE_L	(bit_is_clear(TASTE_L_PIN,TASTE_L_BIT))
#define TASTE_M	(bit_is_clear(TASTE_M_PIN,TASTE_M_BIT))
#define TASTE_R	(bit_is_clear(TASTE_R_PIN,TASTE_R_BIT))

// tasten sind an einzelnen eing�ngen

#define TASTE_M_PORT	PORTD
#define TASTE_M_PIN		PIND
#define TASTE_M_BIT		2
#define TASTE_M_INIT (TASTE_M_PORT|=(1<<TASTE_M_BIT))


/* ### uart ### */
#define UART // wir machen Ausgaben �ber die serielle Schnittstelle
#if defined (__AVR_ATmega168__)
// same as bootloader so reset over serial port works
	#define UART_BAUD_RATE	38400L
//	#define UART_BAUD_RATE	115200
// Baudrate
#elif defined (__AVR_ATmega8__)
//	#define UART_BAUD_RATE	9600L
	#define UART_BAUD_RATE	38400L
	//#define UART_UBRRL	(103) // 9600@16MHz U2X = 0
//	#define UART_UBRRL	(25) // 38400@16MHz U2X = 0
#endif

#endif

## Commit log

2015-03-21 hardware eagle files
    [rt_solder_simple_V1.2.brd, rt_solder_simple_V1.2.sch]
2015-12-03 scale template added and readme update
    [scale_solder.DXF]
2015-12-06 chaged temperature measurement and lcd display stuff
    added define for lcd 2x16 or 1x20
2016-04-23 added temperature gain and offset constants
2016-04-23 Temperature gain and offset adjustment
2016-04-23 added image of pached resistor
2020-06-16 git version display at startup and input voltage mointoring added, bootloader fixes, timout counter display
    [hardware.h, main.c, max-Boot.c]
2024-02-10 part list added
    [rt_solder_simple_V1.2.brd, rt_solder_simple_V1.2.csv, rt_solder_simple_V1.2.ods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]
2024-02-10 added board pdf
2024-02-10 rotated pcb image to match board layout in eagle orientation and added link to brd PDF
2024-02-10 added BOM pdf
    [rt_solder_simple_V1.2.ods]
2024-02-10 added bom pdf to README.md
2024-02-10 README.md changed to relative paths and added main_atmega168.hex build
    [rt_solder_simple_V1.2.ods]
2024-02-10 fixed programming and aadded more bodge resistors for voltage mesurement
    [rt_solder_simple_V1.2.ods]
2024-02-10 README.md and added solder tip pinout
2024-02-10 README.md fixed 100k resistor
2024-10-04 update and added uart menu
    [rt_solder_simple_V1.2.brd, rt_solder_simple_V1.2.sch]
2026-11-02 added v2.0 pcb eagle and v2.1
2026-11-02 added pdf of PCB v2.0
